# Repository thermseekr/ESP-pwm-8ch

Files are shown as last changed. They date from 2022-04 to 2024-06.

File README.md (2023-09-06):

# ESP-PWM-8CH
 
ESP8266/ESP32 based board with 8x PWM output channels.

This board is designed to be driven by an Olimex ESP32-POE, ESP32-POE-ISO or Wemos D1 Mini modules. When using the Wemos D1 Mini the maximum number of outputs is 4, and expect some flickering and frequency oscillation due to the software implementation of the PWMs.

The design considers that the board will be mounted on a PCB DIN rail holder. The dimensions consider the holders offered by the Brazilian manufacturer Metaltex, check [here](https://www.metaltex.com.br/produtos/componentes/suportes/sp7-suporte-para-montagem-de-placa-de-circuito-impresso-em-trilho-din) for details.

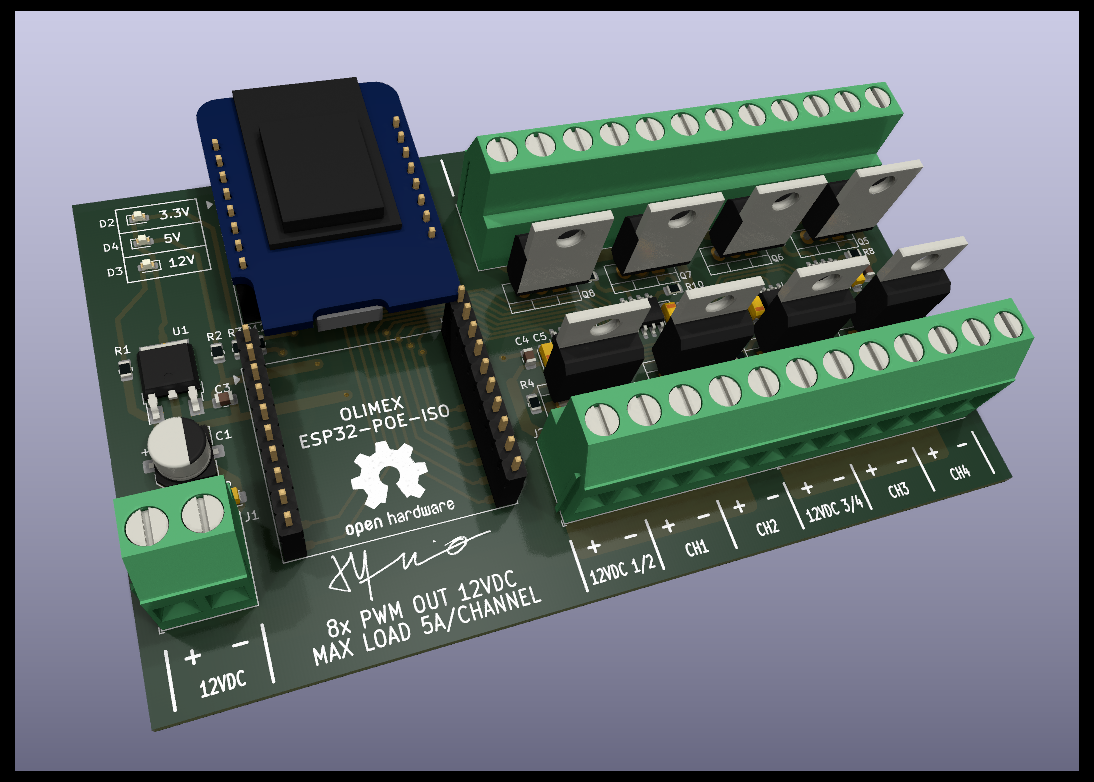
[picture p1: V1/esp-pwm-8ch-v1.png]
ESP-PWM-8CH


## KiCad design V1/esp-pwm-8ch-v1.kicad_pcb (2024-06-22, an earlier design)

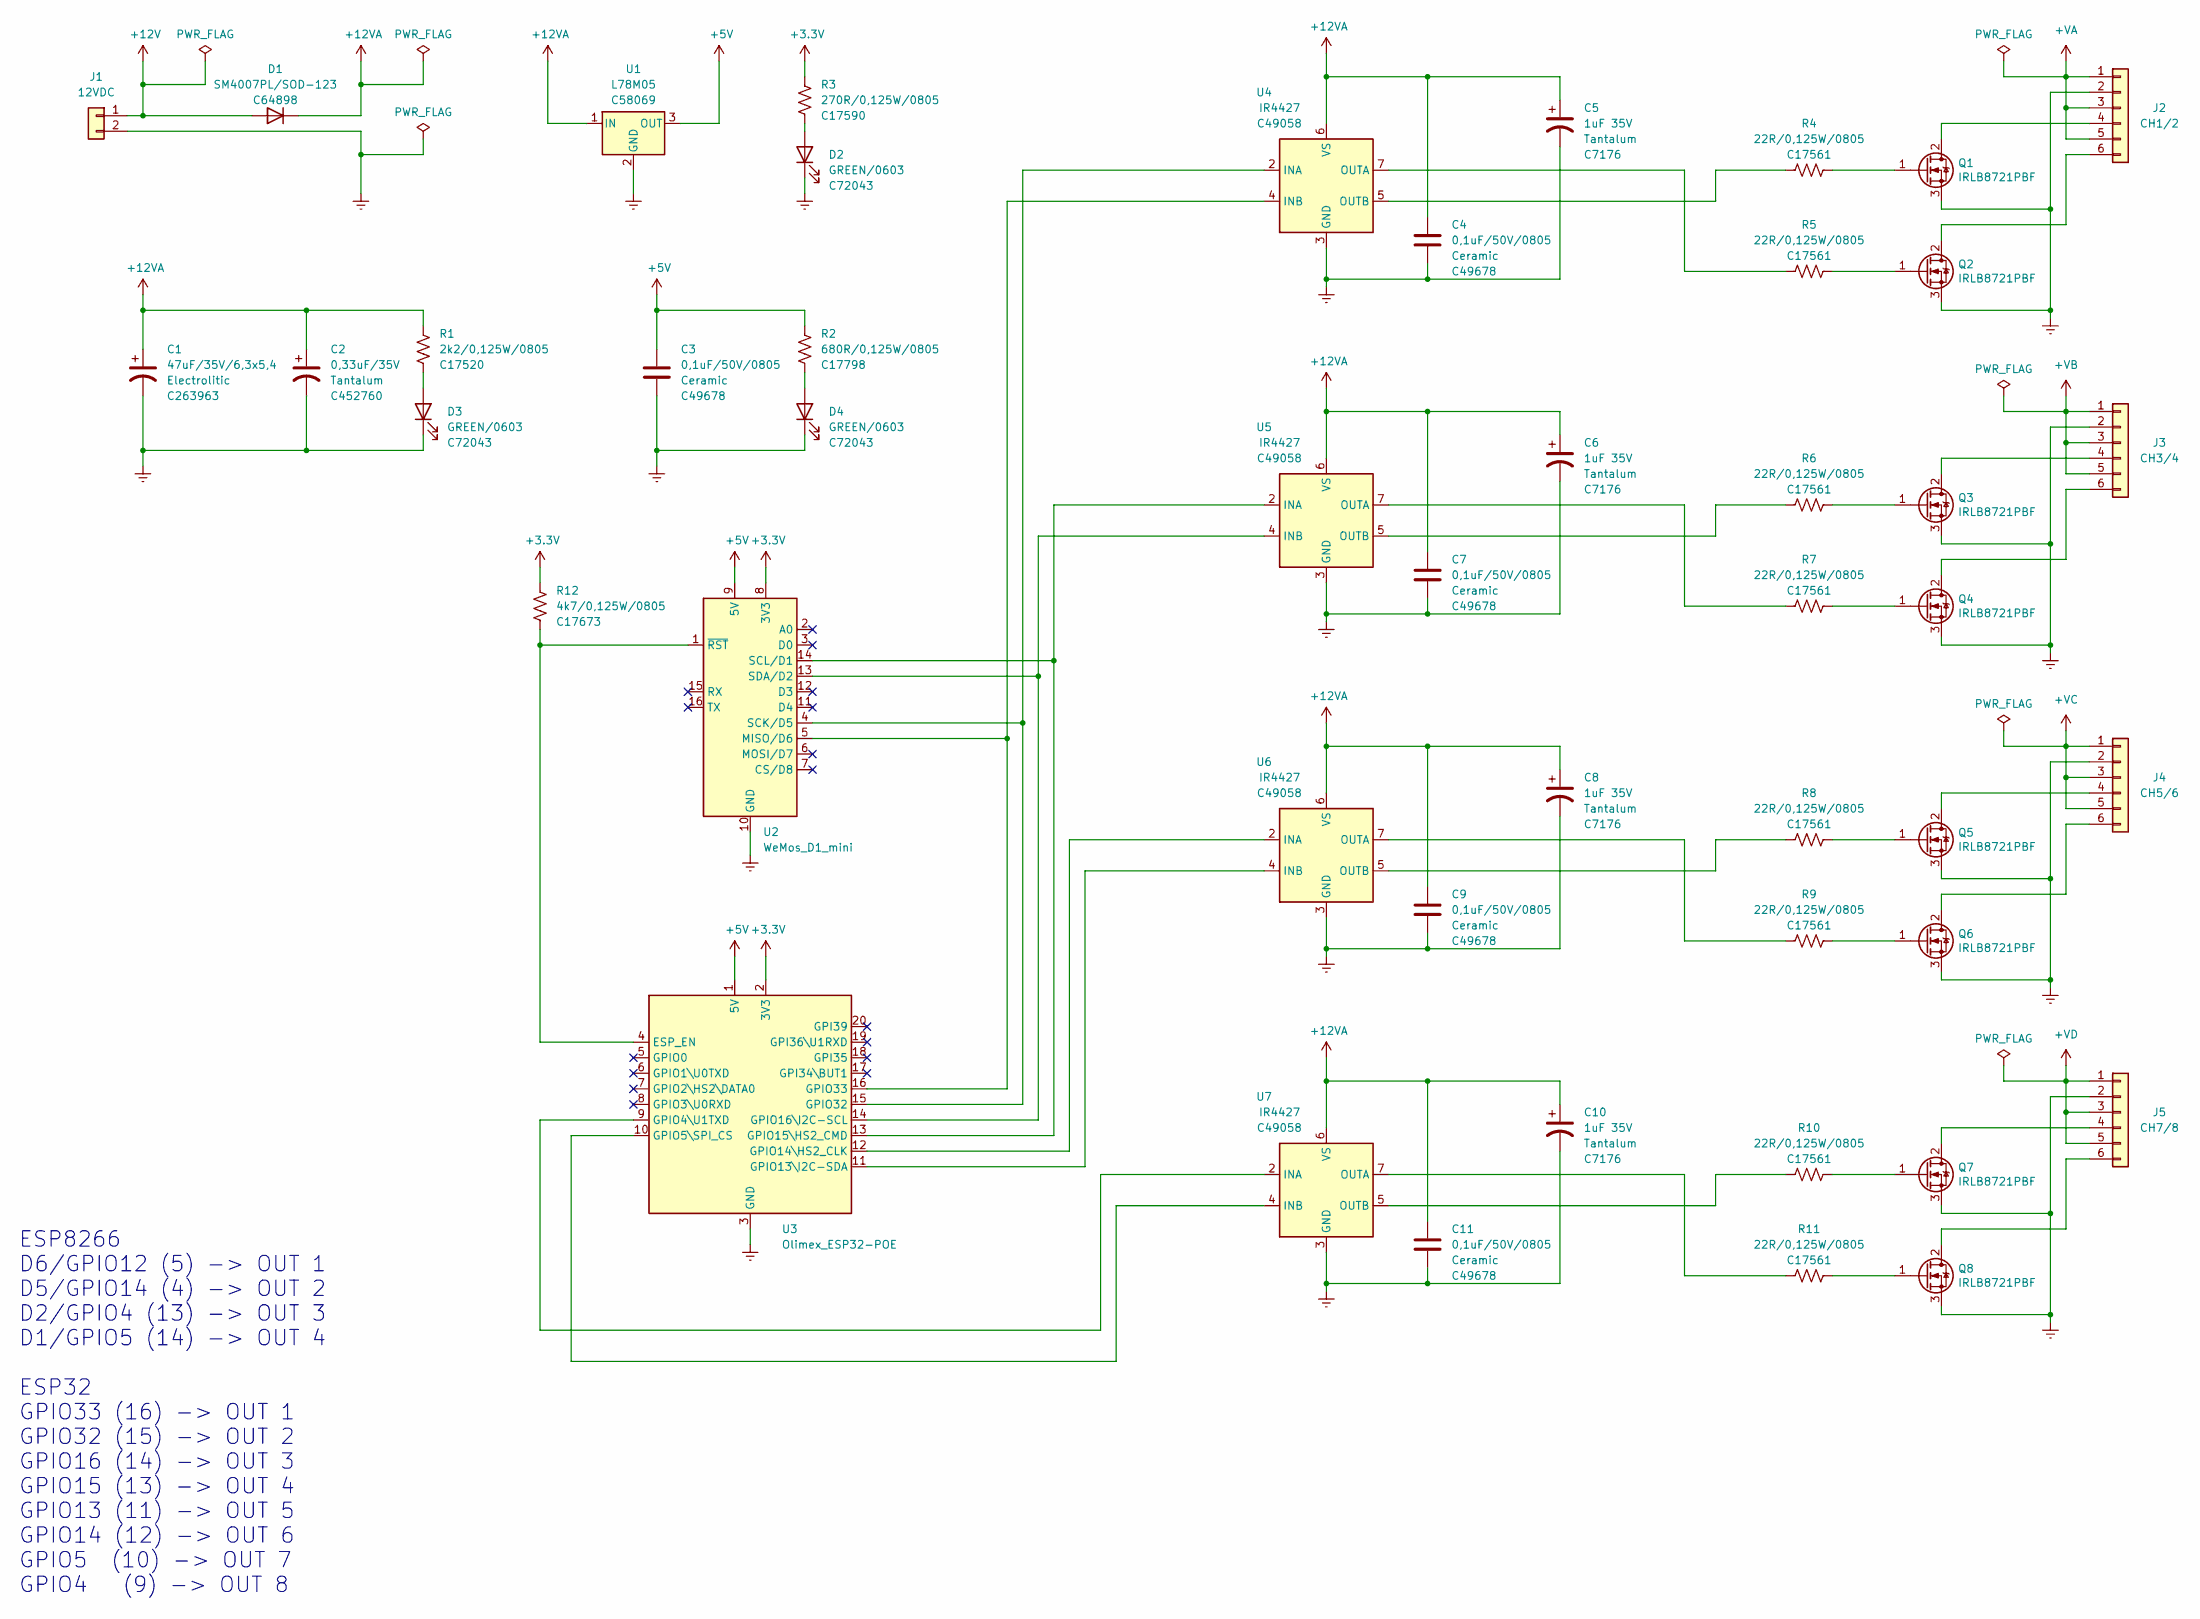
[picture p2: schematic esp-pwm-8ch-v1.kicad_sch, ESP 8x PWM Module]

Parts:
C1: 47uF/35V/6,3x5,4; CP_Elec_6.3x5.4; Mfr PN CK1V470MCRE54; JLCPCB BOM 1
C2: 0,33uF/35V; CP_EIA-3216-18_Kemet-A_Pad1.58x1.35mm_HandSolder; Mfr PN T491A334M035AT; JLCPCB BOM 1
C3, C4, C7, C9, C11: 0,1uF/50V/0805; C_0805_2012Metric; Mfr PN CC0805KRX7R9BB104; JLCPCB BOM 1
C5, C6, C8, C10: 1uF 35V; CP_EIA-3216-18_Kemet-A_Pad1.58x1.35mm_HandSolder; Mfr PN TAJA105K035RNJ; JLCPCB BOM 1
D1: SM4007PL/SOD-123; D_SOD-123; Mfr PN SM4007PL; JLCPCB BOM 1
D2, D3, D4: GREEN/0603; LED_0603_1608Metric; Mfr PN 19-217/GHC-YR1S2/3T; JLCPCB BOM 1
J1: 12VDC; TerminalBlock_Phoenix_MKDS-3-2-5.08_1x02_P5.08mm_Horizontal; Mfr PN BR902V; JLCPCB BOM 0
J2: CH1/2; TerminalBlock_Phoenix_MKDS-3-6-5.08_1x06_P5.08mm_Horizontal; Mfr PN BR902V; JLCPCB BOM 0
J3: CH3/4; TerminalBlock_Phoenix_MKDS-3-6-5.08_1x06_P5.08mm_Horizontal; Mfr PN BR902V; JLCPCB BOM 0
J4: CH5/6; TerminalBlock_Phoenix_MKDS-3-6-5.08_1x06_P5.08mm_Horizontal; Mfr PN BR902V; JLCPCB BOM 0
J5: CH7/8; TerminalBlock_Phoenix_MKDS-3-6-5.08_1x06_P5.08mm_Horizontal; Mfr PN BR902V; JLCPCB BOM 0
Q1, Q2, Q3, Q4, Q5, Q6, Q7, Q8: IRLB8721PBF; TO-220-3_Vertical; Mfr PN IRLB8721PBF; JLCPCB BOM 0
R1: 2k2/0,125W/0805; R_0805_2012Metric; Mfr PN 0805W8F2201T5E; JLCPCB BOM 1
R2: 680R/0,125W/0805; R_0805_2012Metric; Mfr PN 0805W8F6800T5E; JLCPCB BOM 1
R3: 270R/0,125W/0805; R_0805_2012Metric; Mfr PN 0805W8F2700T5E; JLCPCB BOM 1
R4, R5, R6, R7, R8, R9, R10, R11: 22R/0,125W/0805; R_0805_2012Metric; Mfr PN 0805W8F220JT5E; JLCPCB BOM 1
R12: 4k7/0,125W/0805; R_0805_2012Metric; Mfr PN 0805W8F2201T5E; JLCPCB BOM 1
U1: L78M05; TO-252-2; Mfr PN L78M05ABDT-TR; JLCPCB BOM 1
U2: WeMos_D1_mini; WEMOS_D1_mini_light
U3: Olimex_ESP32-POE; Mfr PN ESP32-POE; JLCPCB BOM 0
U4, U5, U6, U7: IR4427; SOIC-8_3.9x4.9mm_P1.27mm; Mfr PN IR4427STRPBF; JLCPCB BOM 1

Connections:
+3V3: R3.1, R12.1, U2.8 (3V3), U3.2 (3V3)
+5V: C3.1, R2.1, U1.3 (OUT), U2.9 (5V), U3.1 (5V)
+12V: D1.2 (A), J1.1
+12VA: C1.1, C2.1, C4.1, C5.1, C6.1, C7.1, C8.1, C9.1, C10.1, C11.1, D1.1 (K), R1.1, U1.1 (IN), U4.6 (VS), U5.6 (VS), U6.6 (VS), U7.6 (VS)
+VA: J2.1, J2.3, J2.5
+VB: J3.1, J3.3, J3.5
+VC: J4.1, J4.3, J4.5
+VD: J5.1, J5.3, J5.5
GNDREF: C1.2, C2.2, C3.2, C4.2, C5.2, C6.2, C7.2, C8.2, C9.2, C10.2, C11.2, D2.1 (K), D3.1 (K), D4.1 (K), J1.2, J2.2, J3.2, J4.2, J5.2, Q1.3 (S), Q2.3 (S), Q3.3 (S), Q4.3 (S), Q5.3 (S), Q6.3 (S), Q7.3 (S), Q8.3 (S), U1.2 (GND), U2.10 (GND), U3.3 (GND), U4.3 (GND), U5.3 (GND), U6.3 (GND), U7.3 (GND)
unnamed: D2.2 (A), R3.2
unnamed: D3.2 (A), R1.2
unnamed: D4.2 (A), R2.2
unnamed: J2.4, Q1.2 (D)
unnamed: J2.6, Q2.2 (D)
unnamed: J3.4, Q3.2 (D)
unnamed: J3.6, Q4.2 (D)
unnamed: J4.4, Q5.2 (D)
unnamed: J4.6, Q6.2 (D)
unnamed: J5.4, Q7.2 (D)
unnamed: J5.6, Q8.2 (D)
unnamed: Q1.1 (G), R4.1
unnamed: Q2.1 (G), R5.1
unnamed: Q3.1 (G), R6.1
unnamed: Q4.1 (G), R7.1
unnamed: Q5.1 (G), R8.1
unnamed: Q6.1 (G), R9.1
unnamed: Q7.1 (G), R10.1
unnamed: Q8.1 (G), R11.1
unnamed: R4.2, U4.5 (OUTB)
unnamed: R5.2, U4.7 (OUTA)
unnamed: R6.2, U5.5 (OUTB)
unnamed: R7.2, U5.7 (OUTA)
unnamed: R8.2, U6.5 (OUTB)
unnamed: R9.2, U6.7 (OUTA)
unnamed: R10.2, U7.5 (OUTB)
unnamed: R11.2, U7.7 (OUTA)
unnamed: R12.2, U2.1 (~RST), U3.4 (ESP_EN)
unnamed: U2.4 (SCK/D5), U3.15 (GPIO32), U4.2 (INA)
unnamed: U2.5 (MISO/D6), U3.16 (GPIO33), U4.4 (INB)
unnamed: U2.13 (SDA/D2), U3.14 (GPIO16\I2C-SCL), U5.4 (INB)
unnamed: U2.14 (SCL/D1), U3.13 (GPIO15\HS2_CMD), U5.2 (INA)
unnamed: U3.9 (GPIO4\U1TXD), U7.2 (INA)
unnamed: U3.10 (GPIO5\SPI_CS), U7.4 (INB)
unnamed: U3.11 (GPIO13\I2C-SDA), U6.4 (INB)
unnamed: U3.12 (GPIO14\HS2_CLK), U6.2 (INA)

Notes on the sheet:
ESP8266 D6/GPIO12 (5) -> OUT 1 D5/GPIO14 (4) -> OUT 2 D2/GPIO4 (13) -> OUT 3 D1/GPIO5 (14) -> OUT 4 ESP32 GPIO33 (16) -> OUT 1 GPIO32 (15) -> OUT 2 GPIO16 (14) -> OUT 3 GPIO15 (13) -> OUT 4 GPIO13 (11) -> OUT 5 GPIO14 (12) -> OUT 6 GPIO5 (10) -> OUT 7 GPIO4 (9) -> OUT 8

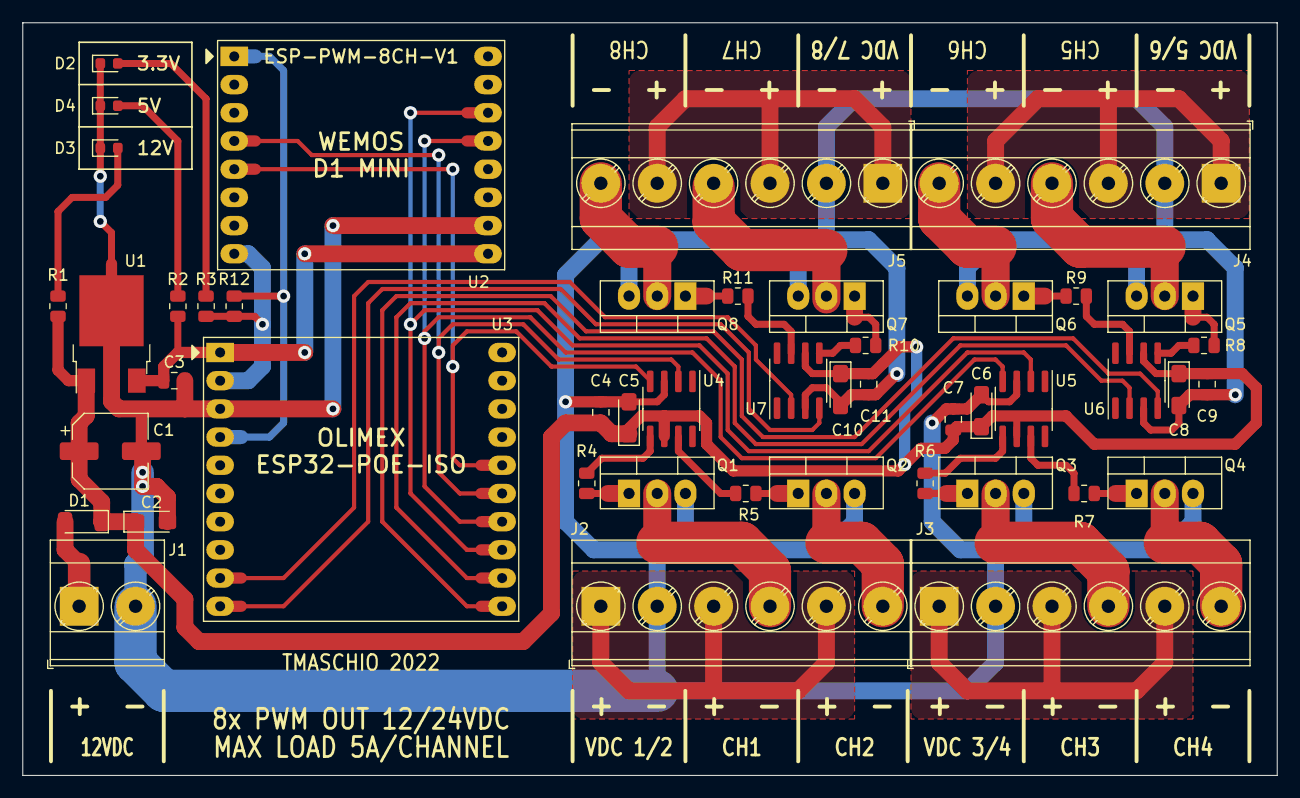
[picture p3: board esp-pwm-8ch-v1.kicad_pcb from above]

Board: 2 copper layers, 113.0 x 67.8 mm, 47 parts (0 on the bottom side), 45 nets.

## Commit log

2022-03-29 work in progress
    [ESP-pwm_8ch-V1-B_Cu.gbl, ESP-pwm_8ch-V1-B_Mask.gbs, ESP-pwm_8ch-V1-B_Paste.gbp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]
2022-03-29 cleaning up
    [ESP-pwm_8ch-V1-OFF.kicad_pcb, ESP-pwm_8ch-V1-OFF.kicad_sch]
2022-04-01 Updated MOSFET gate resistor
    [ESP-pwm_8ch-V1.kicad_pcb, ESP-pwm_8ch-V1.kicad_sch]
2022-04-01 Added ESP8266
    [ESP-pwm_8ch-V1.kicad_pcb, ESP-pwm_8ch-V1.kicad_sch]
2022-04-01 Reset pull up to +3.3V
    [ESP-pwm_8ch-V1.kicad_pcb, ESP-pwm_8ch-V1.kicad_sch]
2022-04-01 Update board images
2022-04-01 PCB tweaks
    [ESP-pwm_8ch-V1.kicad_pcb, ESP-pwm_8ch-V1.kicad_sch]
2022-04-03 rename files to new schema
    [ESP-pwm-8ch-V1.kicad_pcb, ESP-pwm-8ch-V1.kicad_sch]
2022-04-04 Separated driver power lines from loads
    [ESP-pwm-8ch-V1.kicad_pcb, ESP-pwm-8ch-V1.kicad_sch]
2023-05-20 Kicad version update
    [ESP-pwm-8ch-V1.kicad_pcb, ESP-pwm-8ch-V1.kicad_sch]
2023-05-20 Correct icloud erros
    [ESP-pwm-8ch-V1.kicad_pcb, ESP-pwm-8ch-V1.kicad_sch]
2023-08-20 updated connectors
    [ESP-pwm-8ch-V1.kicad_pcb, ESP-pwm-8ch-V1.kicad_sch]
2023-09-06 Rename to lowercase
    [small-esp-pwm-8ch-v1.kicad_pcb, small-esp-pwm-8ch-v1.kicad_sch]
2024-06-22 Update Kicad version
    [esp-pwm-8ch-v1.kicad_pcb, esp-pwm-8ch-v1.kicad_sch, esp-pwm-8ch-v2.kicad_sch]
